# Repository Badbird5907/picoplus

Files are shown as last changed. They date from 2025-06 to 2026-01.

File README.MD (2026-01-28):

# Pico+
[Video Demo](https://www.youtube.com/shorts/jsLF4tYyZew)

This is my take on the Raspberry Pi Pico 2. It features:
- RP2350A
- USB C
- A very stable 3.3V power supply (TPS7A20)
- A WS2812 LED
- A reset button (!!!)
- Large SPI flash on SPI0
- Large PSRAM chip on SPI1

I wanted to make this project as the stock pico is kinda underpowered, and I wanted to make a overkill version. While making this project, I did have to reduce my scope by removing the I2C EEPROM and some other features. However, I'm really happy with the resulting board.

PCB
schematic




# BOM
Note: this is more or less a direct export of my LCSC cart. Most parts have a minimum order quantity, hence the large quantities. 

|Name |Description |Quantity|Unit Price($)|Total (USD)|
|---|---|---|---|---|
|0402WGF1001TCE |62.5mW Thick Film Resistor 50V ±100ppm/℃ ±1% 1kΩ 0402 Chip Resistor - Surface Mount ROHS |100 |0.0006 |0.06 |
|0402CG150J500NT |50V 15pF C0G ±5% 0402 Multilayer Ceramic Capacitors MLCC - SMD/SMT ROHS |100 |0.001 |0.1 |
|CC0201KRX5R6BB104 |10V 100nF X5R ±10% 0201 Multilayer Ceramic Capacitors MLCC - SMD/SMT ROHS |100 |0.0011 |0.11 |
|W25Q128JVPIQ |SPI 133MHz WSON-8-EP(5x6) NOR FLASH ROHS |1 |0.9177 |0.92 |
|ABM8-272-T3 |SMD3225-4P Crystals ROHS |1 |0.3731 |0.37 |
|0603WAF100KT5E |100mW Thick Film Resistor 75V ±1% ±400ppm/℃ 1Ω 0603 Chip Resistor - Surface Mount ROHS |100 |0.0016 |0.16 |
|KT-0805G |Emerald Green 0805 LED Indication - Discrete ROHS |50 |0.011 |0.55 |
|CL05A475MP5NRNC |10V 4.7uF X5R ±20% 0402 Multilayer Ceramic Capacitors MLCC - SMD/SMT ROHS |50 |0.0052 |0.26 |
|0402WGF2000TCE |62.5mW Thick Film Resistor 50V ±100ppm/℃ ±1% 200Ω 0402 Chip Resistor - Surface Mount ROHS |100 |0.0006 |0.06 |
|0402WGF330JTCE |62.5mW Thick Film Resistor 50V ±100ppm/℃ ±1% 33Ω 0402 Chip Resistor - Surface Mount ROHS |100 |0.0006 |0.06 |
|0402WGF4700TCE |62.5mW Thick Film Resistor 50V ±100ppm/℃ ±1% 470Ω 0402 Chip Resistor - Surface Mount ROHS |100 |0.0006 |0.06 |
|0402WGF1002TCE |62.5mW Thick Film Resistor 50V ±100ppm/℃ ±1% 10kΩ 0402 Chip Resistor - Surface Mount ROHS |100 |0.0006 |0.06 |
|0402WGF5101TCE |62.5mW Thick Film Resistor 50V ±100ppm/℃ ±1% 5.1kΩ 0402 Chip Resistor - Surface Mount ROHS |100 |0.0005 |0.05 |
|TYPE-C 16PIN 2MD(073) |3A USB 3.1 1 Surface Mount, Right Angle 16P Female -25℃~+85℃ Type-C SMD USB Connectors ROHS |10 |0.0549 |0.55 |
|XL-5050RGBC-WS2812B |SMD5050 RGB LEDs(Built-in IC) ROHS |10 |0.049 |0.49 |
|TPS7A2033PDBVR |65dB@(100kHz) 300mA Fixed 3.3V Positive 6V SOT-23-5 Voltage Regulators - Linear, Low Drop Out (LDO) Regulators ROHS |5 |0.2081 |1.04 |
|APS6404L-3SQR-ZR |USON-8L DRAM ROHS |1 |1.1433 |1.14 |
|RP2350A |QFN-60-EP(7x7) Microcontrollers (MCU/MPU/SOC) ROHS |5 |1.6544 |1.6544 |
|AOTA-B201610S3R3-101-T|0806 Power Inductors ROHS |5 |0.2584 |1.29 |
|0201WMF270JTEE |50mW Thick Film Resistor 25V ±1% ±200ppm/℃ 27Ω 0201 Chip Resistor - Surface Mount ROHS |100 |0.0008 |0.08 |
|TS-1088-AR02016 |Without Bracket 50mA 4mm 100,000 Cycles 12V 1.6N 3mm 2mm Round Button Surface Mount,Vertical SPST SMD Tactile Switches ROHS |10 |0.0434 |0.43 |
|B5819W SL |40V 600mV@1A 1A SOD-123 Schottky Diodes ROHS |20 |0.0233 |0.47 |
|LCSC Shipping | | | |12.12 |
|PCB | | | |56.1 |
|Stencil | | | |7 |
|JLC Shipping | | | |7.78 |
| | | | | |
|TOTAL | | | |92.9644 |

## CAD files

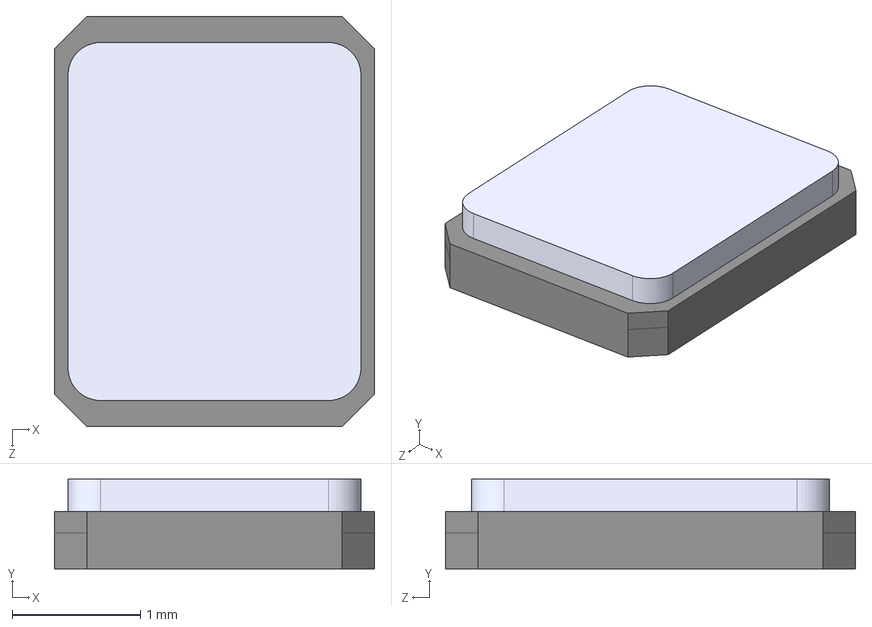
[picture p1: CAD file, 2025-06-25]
PCB/Components/ABM8-272-T3.STEP
2.50 x 0.7 x 3.20 mm

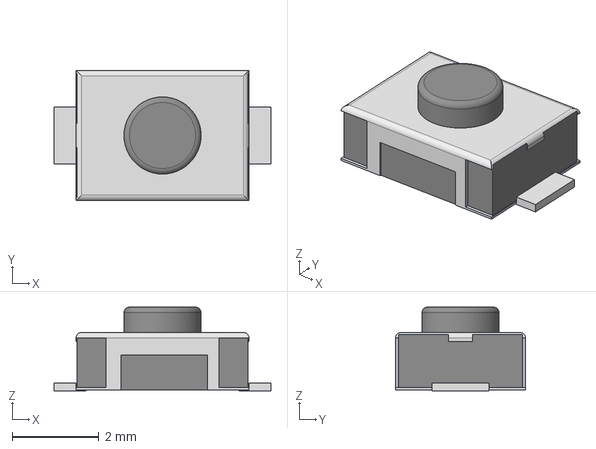
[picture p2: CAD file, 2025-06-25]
PCB/Components/3x4x2mm - 2 Pad.stp
5.00 x 3.00 x 1.93 mm

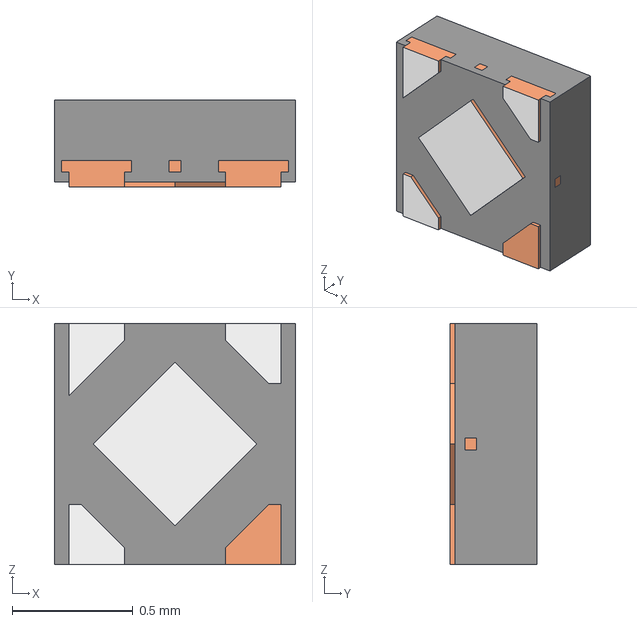
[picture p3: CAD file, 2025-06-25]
PCB/Components/DQN0004A.stp
1.00 x 0.36 x 1.00 mm
MOLD-SNB04A
FRAME-SNB04A

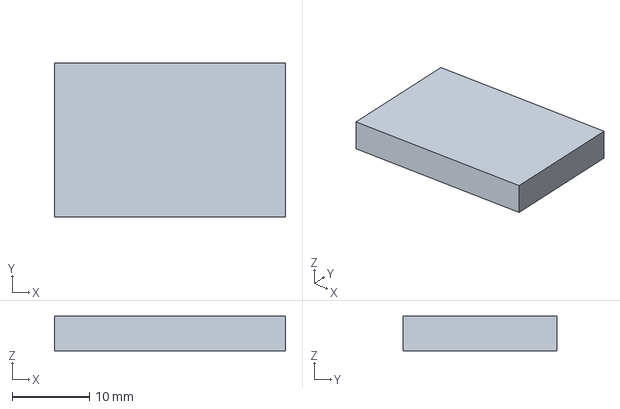
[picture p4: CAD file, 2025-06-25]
PCB/Components/AP Memory APS6404L-3SQR-ZR.step
30.0 x 20.0 x 4.50 mm

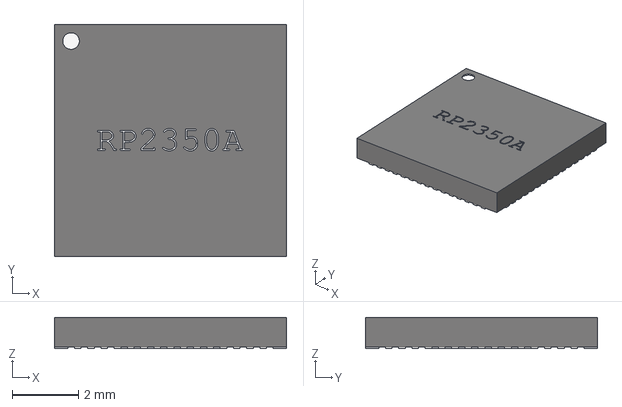
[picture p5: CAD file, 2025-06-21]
PCB/Components/RP2350_QFN60.step
7.00 x 7.00 x 0.95 mm

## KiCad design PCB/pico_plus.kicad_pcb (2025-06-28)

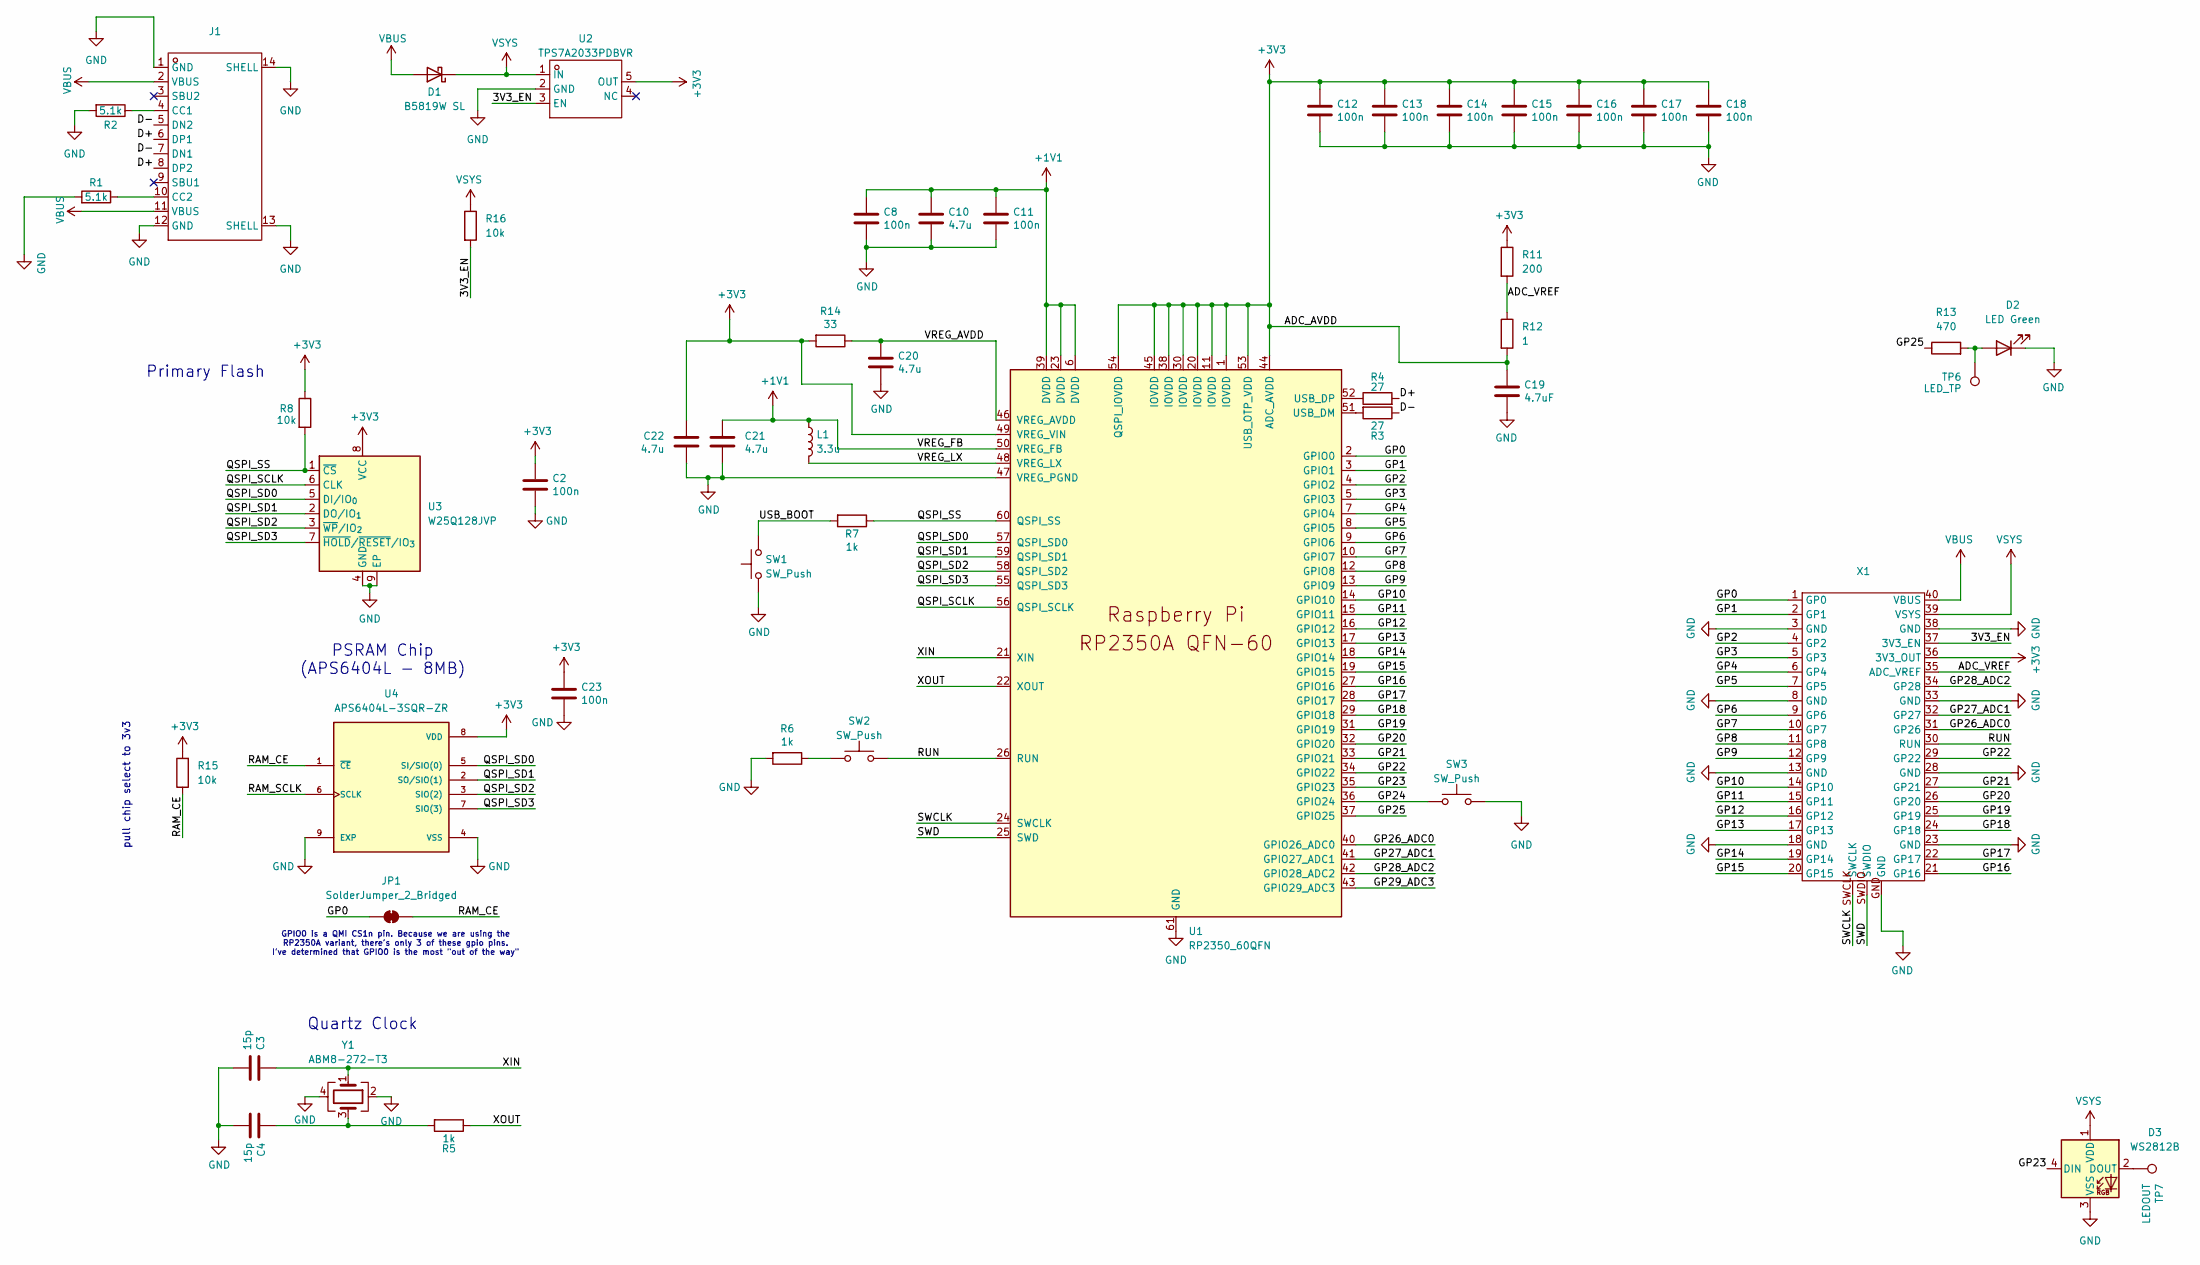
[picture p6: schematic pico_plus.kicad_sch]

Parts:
C2, C8, C11, C12, C13, C14, C15, C16, C17, C18, C23: 100n; C_0201_0603Metric
C3, C4: 15p; C_0402_1005Metric
C10, C20: 4.7u; C_0402_1005Metric
C19: 4.7uF; C_0402_1005Metric
C21, C22: 4.7u; C_0402_1005Metric_small_pads
D1: B5819W SL; D_SOD-123
D2: LED Green; LED_0805_2012Metric
D3: WS2812B; LED_WS2812B_PLCC4_5.0x5.0mm_P3.2mm
J1: USB-C-SMD_TYPE-C-6PIN-2MD-073; Manufacturer Part TYPE-C 16PIN 2MD(073); LCSC Part Name Type-C 母 卧贴
JP1: SolderJumper_2_Bridged; SolderJumper-2_P1.3mm_Bridged2Bar_RoundedPad1.0x1.5mm
L1: 3.3u; L_pol_2016
R1, R2: 5.1k; R_0402_1005Metric
R3, R4: 27; R_0201_0603Metric
R5, R6, R7: 1k; R_0402_1005Metric
R8, R15, R16: 10k; R_0402_1005Metric
R11: 200; R_0402_1005Metric
R12: 1; R_0603_1608Metric
R13: 470; R_0402_1005Metric
R14: 33; R_0402_1005Metric
SW1, SW2, SW3: SW_Push; SW-SMD_L3.9-W3.0-P4.45
TP6: LED_TP; TestPoint_Pad_D1.0mm
TP7: LEDOUT; TestPoint_Pad_D1.0mm
U1: RP2350_60QFN; RP2350-QFN-60-1EP_7x7_P0.4mm_EP3.4x3.4mm_ThermalVias
U2: TPS7A2033PDBVR; SOT-23-5_L2.9-W1.6-P0.95-LS2.8-BR; Manufacturer Part TPS7A2033PDBVR; LCSC Part Name 具有高 PSRR 的 300mA、超低噪声、低 IQ、低压降 (LDO) 线性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
U3: W25Q128JVP; WSON-8-1EP_6x5mm_P1.27mm_EP3.4x4.3mm
U4: APS6404L-3SQR-ZR; PSON50P200X300X50-9N; PARTREV 2.3
X1: Pico_Castellated_Holes
Y1: ABM8-272-T3; XTAL_ABM8-272-T3

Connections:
+1V1: C8.1, C10.1, C11.1, C21.1, L1.1, U1.6 (DVDD), U1.23 (DVDD), U1.39 (DVDD), U1.50 (VREG_FB)
+3V3: C2.1, C12.1, C13.1, C14.1, C15.1, C16.1, C17.1, C18.1, C19.1, C22.1, C23.1, R8.1, R11.1, R12.2, R14.2, R15.2, U1.1 (IOVDD), U1.11 (IOVDD), U1.20 (IOVDD), U1.30 (IOVDD), U1.38 (IOVDD), U1.44 (ADC_AVDD), U1.45 (IOVDD), U1.49 (VREG_VIN), U1.53 (USB_OTP_VDD), U1.54 (QSPI_IOVDD), U2.5 (OUT), U3.8 (VCC), U4.8 (VDD), X1.36 (3V3_OUT)
/3V3_EN: R16.2, U2.3 (EN), X1.37 (3V3_EN)
/ADC_VREF: R11.2, R12.1, X1.35 (ADC_VREF)
/D+: J1.6 (DP1), J1.8 (DP2), R4.2
/D-: J1.5 (DN2), J1.7 (DN1), R3.1
/GP0: JP1.1 (A), U1.2 (GPIO0), X1.1 (GP0)
/GP1: U1.3 (GPIO1), X1.2 (GP1)
/GP2: U1.4 (GPIO2), X1.4 (GP2)
/GP3: U1.5 (GPIO3), X1.5 (GP3)
/GP4: U1.7 (GPIO4), X1.6 (GP4)
/GP5: U1.8 (GPIO5), X1.7 (GP5)
/GP6: U1.9 (GPIO6), X1.9 (GP6)
/GP7: U1.10 (GPIO7), X1.10 (GP7)
/GP8: U1.12 (GPIO8), X1.11 (GP8)
/GP9: U1.13 (GPIO9), X1.12 (GP9)
/GP10: U1.14 (GPIO10), X1.14 (GP10)
/GP11: U1.15 (GPIO11), X1.15 (GP11)
/GP12: U1.16 (GPIO12), X1.16 (GP12)
/GP13: U1.17 (GPIO13), X1.17 (GP13)
/GP14: U1.18 (GPIO14), X1.19 (GP14)
/GP15: U1.19 (GPIO15), X1.20 (GP15)
/GP16: U1.27 (GPIO16), X1.21 (GP16)
/GP17: U1.28 (GPIO17), X1.22 (GP17)
/GP18: U1.29 (GPIO18), X1.24 (GP18)
/GP19: U1.31 (GPIO19), X1.25 (GP19)
/GP20: U1.32 (GPIO20), X1.26 (GP20)
/GP21: U1.33 (GPIO21), X1.27 (GP21)
/GP22: U1.34 (GPIO22), X1.29 (GP22)
/GP23: D3.4 (DIN), U1.35 (GPIO23)
/GP24: SW3.1, U1.36 (GPIO24)
/GP25: R13.1, U1.37 (GPIO25)
/GP26_ADC0: U1.40 (GPIO26_ADC0), X1.31 (GP26)
/GP27_ADC1: U1.41 (GPIO27_ADC1), X1.32 (GP27)
/GP28_ADC2: U1.42 (GPIO28_ADC2), X1.34 (GP28)
/GP29_ADC3: U1.43 (GPIO29_ADC3)
/QSPI_SCLK: U1.56 (QSPI_SCLK), U3.6 (CLK)
/QSPI_SD0: U1.57 (QSPI_SD0), U3.5 (DI/IO_{0}), U4.5 (SI/SIO(0))
/QSPI_SD1: U1.59 (QSPI_SD1), U3.2 (DO/IO_{1}), U4.2 (SO/SIO(1))
/QSPI_SD2: U1.58 (QSPI_SD2), U3.3 (~WP/IO_{2}), U4.3 (SIO(2))
/QSPI_SD3: U1.55 (QSPI_SD3), U3.7 (~HOLD/~RESET/IO_{3}), U4.7 (SIO(3))
/QSPI_SS: R7.1, R8.2, U1.60 (QSPI_SS), U3.1 (~CS)
/RAM_CE: JP1.2 (B), R15.1, U4.1 (~CE)
/RAM_SCLK: U4.6 (SCLK)
/RUN: SW2.2, U1.26 (RUN), X1.30 (RUN)
/SWCLK: U1.24 (SWCLK), X1.SWCLK
/SWD: U1.25 (SWD), X1.SWDIO
/USB_BOOT: R7.2, SW1.2
/VREG_AVDD: C20.1, R14.1, U1.46 (VREG_AVDD)
/VREG_LX: L1.2, U1.48 (VREG_LX)
/XIN: C3.1, U1.21 (XIN), Y1.1
/XOUT: R5.1, U1.22 (XOUT)
GND: C2.2, C3.2, C4.2, C8.2, C10.2, C11.2, C12.2, C13.2, C14.2, C15.2, C16.2, C17.2, C18.2, C19.2, C20.2, C21.2, C22.2, C23.2, D2.1 (K), D3.3 (VSS), J1.1 (GND), J1.12 (GND), J1.13 (SHELL), J1.14 (SHELL), R1.2, R2.2, R6.2, SW1.1, SW3.2, U1.47 (VREG_PGND), U1.61 (GND), U2.2 (GND), U3.4 (GND), U3.9 (EP), U4.4 (VSS), U4.9 (EXP), X1.3 (GND), X1.8 (GND), X1.13 (GND), X1.18 (GND), X1.23 (GND), X1.28 (GND), X1.33 (GND), X1.38 (GND), X1.GND, Y1.2, Y1.4
unnamed: C4.1, R5.2, Y1.3
unnamed: D2.2 (A), R13.2, TP6.1
unnamed: D3.2 (DOUT), TP7.1
unnamed: J1.4 (CC1), R2.1
unnamed: J1.10 (CC2), R1.1
unnamed: R6.1, SW2.1
unnamed: R3.2, U1.51 (USB_DM)
unnamed: R4.1, U1.52 (USB_DP)
VBUS: D1.2 (A), J1.2 (VBUS), J1.11 (VBUS), X1.40 (VBUS)
VSYS: D1.1 (K), D3.1 (VDD), R16.1, U2.1 (IN), X1.39 (VSYS)

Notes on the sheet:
Primary Flash
Quartz Clock
PSRAM Chip (APS6404L - 8MB)
pull chip select to 3v3
GPIO0 is a QMI CS1n pin. Because we are using the RP2350A variant, there's only 3 of these gpio pins. I've determined that GPIO0 is the most "out of the way"

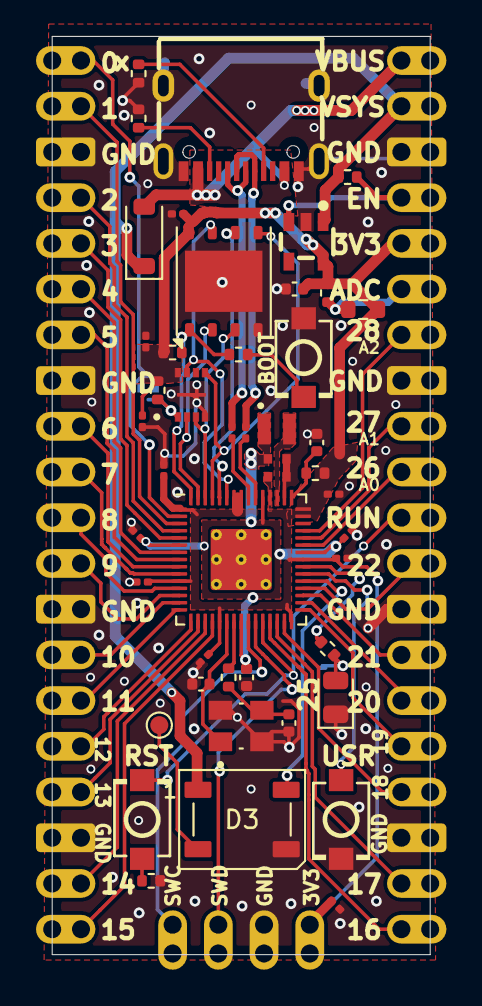
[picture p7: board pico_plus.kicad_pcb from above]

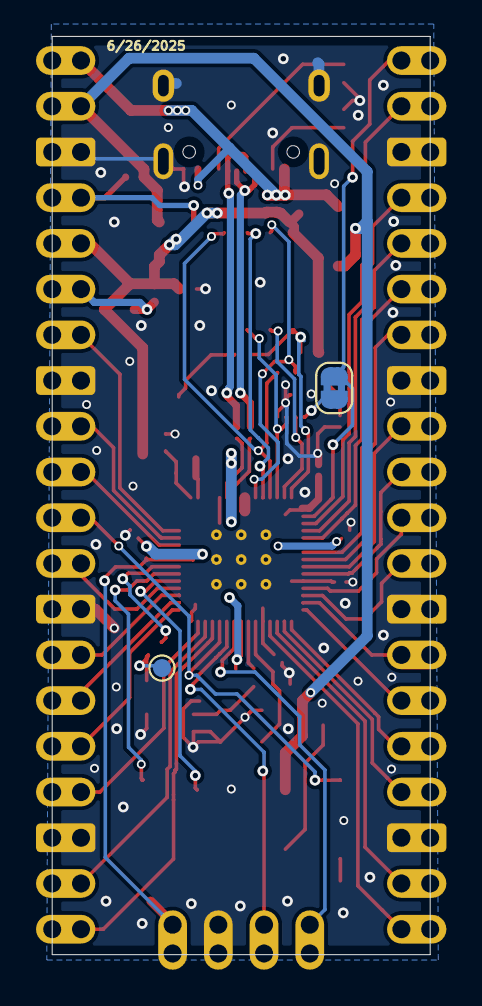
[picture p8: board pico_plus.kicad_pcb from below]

Board: 2 copper layers, 21.0 x 51.0 mm, 49 parts (2 on the bottom side), 61 nets.

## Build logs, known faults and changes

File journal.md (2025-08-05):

Total Time Spent: 39h

# 6/20
Time spent: 4h
Read through the [hardware design with rp2350](https://datasheets.raspberrypi.com/rp2350/hardware-design-with-rp2350.pdf) document, and some of the rp2350 datasheet, and got started with the design.

Since the RP2350 supports dual SPI chips, i'm looking into adding an SPI EEPROM like the AT25M02 to the design, which will allow for more flexibility with storage.

# 6/21
Time spent: 5h
I did some research into how SPI works, like the chip select pin, and how it works on the RP2350. I think I'm going to swap the RP2350**A** for the RP2350**B**, for more gpio and flexibility for on-board features. I'm probably also going create another devboard in a larger formfactor that allows breaks out ALL the pins on the RP2350**B**, and maybe some more overkill things :)
I'll probably call it either the Pico++ or the Pico Max.

I've also made the footprint for the pin headers, including the castellated pins.


# 6/22
Time spent: 4h
Finished the schematic design, and looked at the pico 2 source schematic to see if I made any errors. I've also sourced most of the parts on LCSC. The preliminary cost is about $120 USD (ENIG + Standard PCBA)

# 6/23
Time spent: 1h
Added SWD debug pads to the design. I've also started working on the PCB layout and routing.



# 6/24
Time spent: 7h
Sat at my desk and made some tweaks to the schematic- the I2C EEPROM chip was removed because there just wasn't enough space on the board, and it costs quite a bit. I then decided to delete all traces and vias and start again. I've fully routed the board in a couple hours.


# 6/25

--
Time spent: 6h
Did this all in a couple hours at a coffee shop. I redid the power layout and finished the PCB. On to sourcing parts now
--

--
Time spent: 4h
Redid and moved around a bit of the power supply, and then optimized the BOM and things for PCBA. I then realized the project would be overbudget, so I decided to get a hotplate and reflow the parts myself, which is much cheaper. I then created the master BOM for LCSC and JLCPCB.
I decided to get the hotplate off amazon as the price is only $1 more than AliExpress.

# 7/9

Time spent: 5h

The parts arrived and I reflowed the pcb, it works!
PS. 0201 components are HELLLISH to deal with





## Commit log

2025-06-21 Some work on schematic
    [pico_plus.kicad_sch]
2025-06-22 a lot of work
    [pico_plus.kicad_pcb, pico_plus.kicad_sch]
2025-06-23 finish schematic
    [pico_plus.kicad_pcb, pico_plus.kicad_sch]
2025-06-24 work on pcb
    [pico_plus.kicad_pcb, pico_plus.kicad_sch]
2025-06-25 finish routing
    [pico_plus.kicad_pcb, pico_plus.kicad_sch]
2025-06-25 finish pcb
    [3x4x2mm - 2 Pad.stp, ABM8-272-T3.STEP, AP Memory APS6404L-3SQR-ZR.step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]
2025-06-26 schematic fix
    [pico_plus.kicad_sch]
2025-06-26 finish up pcb + bom
    [pico_plus.kicad_pcb, pico_plus.kicad_sch]
2025-06-27 update bom
    [pico_plus.kicad_pcb]
2025-06-28 forgot bom.csv
    [BOM.csv]
2026-01-28 Update images in README
    Updated PCB image link and added schematic image.
